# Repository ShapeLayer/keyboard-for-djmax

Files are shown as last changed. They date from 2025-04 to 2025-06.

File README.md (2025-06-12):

# Keyboard for DJMAX RESPECT V

_A project task for &lt;IoT Computing&gt; lecture in computer engineering undergraduate course program._

A keyboard for a PC rhythm game, like DJMAX RESPECT V, EZ2ON, etc that supports key input of up to 10 keys, a knob module(usual rotary encoder), and an I2C OLED display module.

## Getting Started

The controller sketch is designed to have compatibility with any Arduino board that supports the `Keyboard` library like Arduino Leonardo.

However, only Arduino Leonardo has been implemented and tested in reality. So it is recommended to use Arduino Leonardo for this project.

### Hardware Requirements
- Arduino board supports `Keyboard` library  
- 10x switches  
    _(If there aren't enough keyboard key switches, you can use push buttons)_
- 1x rotary encoder
- 1x I2C OLED display module  
    _(I used a 128x32 pixels OLED display. If you use a different size, you may need to adjust the display code.)_

A controller processes the key input designed as a 5x2 key matrix. You have to implement the key matrix circuit. The circuit diagram I used is available in the [`circuits`](./circuits/) directory.

### Printing the Case

If you want to print the case, you can find the 3D model files in the [`models`](./models/) directory.

### Software Requirements

- [u8g2 library](https://github.com/olikraus/u8g2) for OLED display  
    Install it through Arduino Library Manager in Arduino IDE. or refer [`INSTALL.ps1`](./INSTALL.ps1)  
- Configuration
    - [`controller/config.h`](./controller/config.h)  
        Configure the pin numbers of the switches, key output mapping, and others.

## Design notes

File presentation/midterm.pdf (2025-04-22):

# PC 리듬게임을 위한

# 리듬게임 컨트롤러

### 사용 중인 키보드로부터

## 「DJMAX RESPECT V」 플레이 컨트롤러 분리하기

공과대학 컴퓨터정보통신공학과

## 214823 박종현

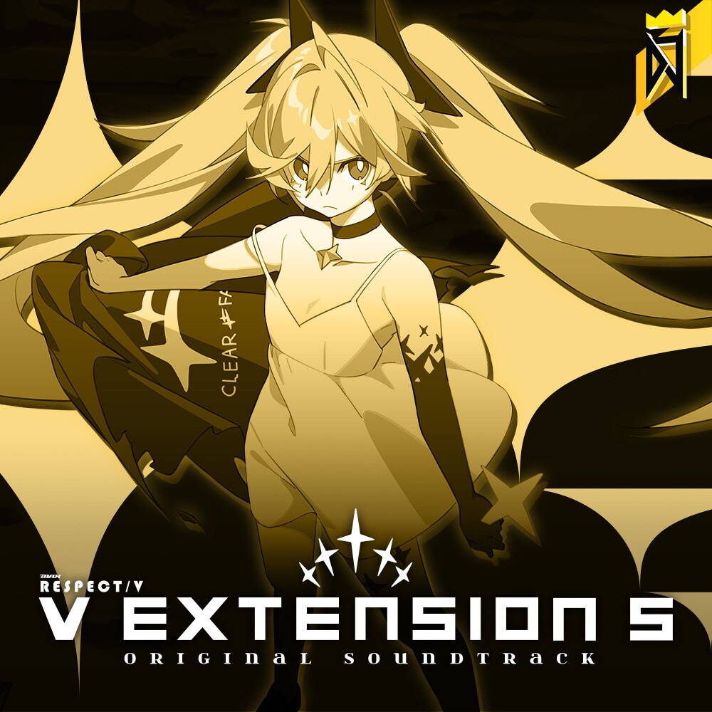
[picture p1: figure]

Source: Rocky Studio

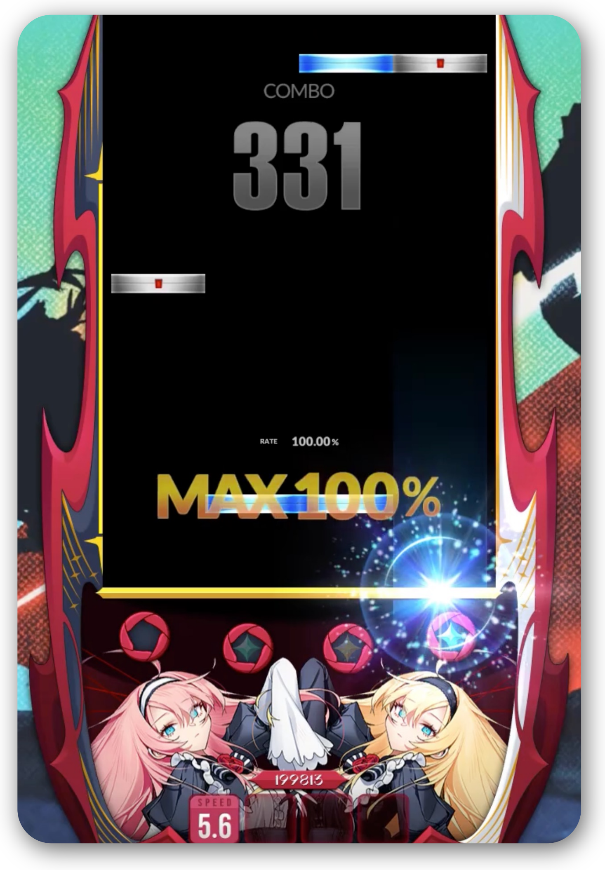
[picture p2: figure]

배경

- 리듬게임은 리듬과 타이밍에 맞춰 곡을 연주
- 정확한 버튼 입력 타이밍을 놓치지 않으려고
강하게 입력

배경

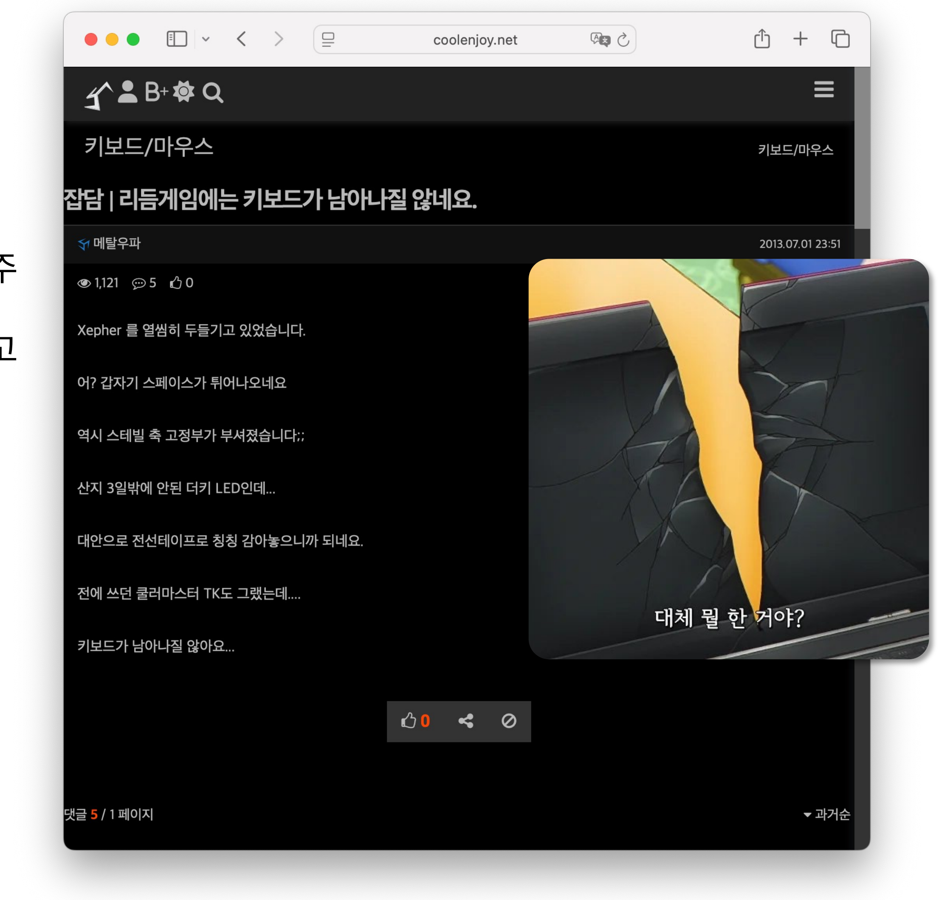
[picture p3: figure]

- 리듬게임은 리듬과 타이밍에 맞춰 곡을 연주
- 정확한 버튼 입력 타이밍을 놓치지 않으려고
강하게 입력
- 키보드 스위치에 무리가 가는 일
- 리듬게임 입력으로 사용하는 키보드 키의
스위치는 다른 키보다 빠르게 소모됨

목표

### - 일반 목적으로 사용하는 키보드와

## 리듬게임 키 입력용 입력 장치의

분리

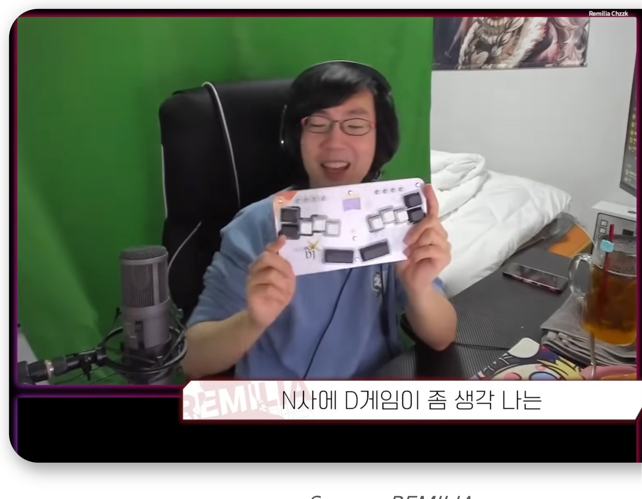
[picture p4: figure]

Source: REMILIA

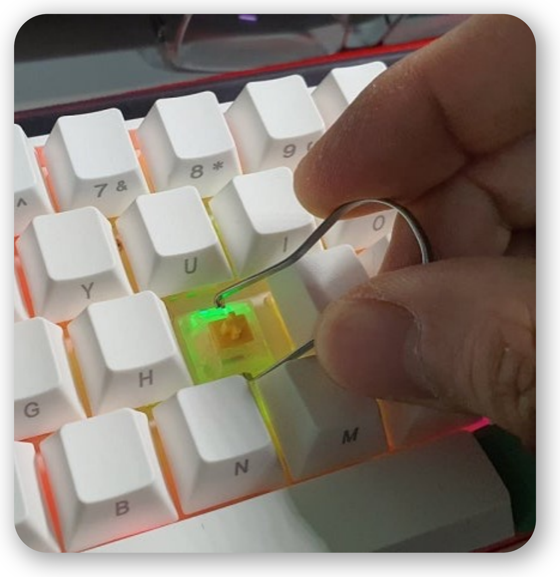
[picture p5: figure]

# 진행 계획

1. 이미 고장난 키보드에서 정상 작동하는 스위 치 추출
2. 추출한 스위치를 아두이노와 연결
3. 스위치 입력 시 아두이노가 PC에 키보드 입 력 신호를 발생시키는 코드 작성
- 사용할 센서: 키보드 클릭 스위치 10개 전후

# 예상되는 문제

- 키보드의 스위치를 아두이노에서 사용할 수 있는가? 내부 회로가 단순한 푸시 버튼 구조가 아닌 경우
- 아두이노가 키보드 입력 신호를 발생할 수 있는가?

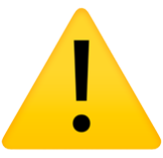
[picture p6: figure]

아두이노에서 연결된 PC로 키보드 입력 신호를 전송하 ⚠ 지 못할 경우

# 확인된 문제

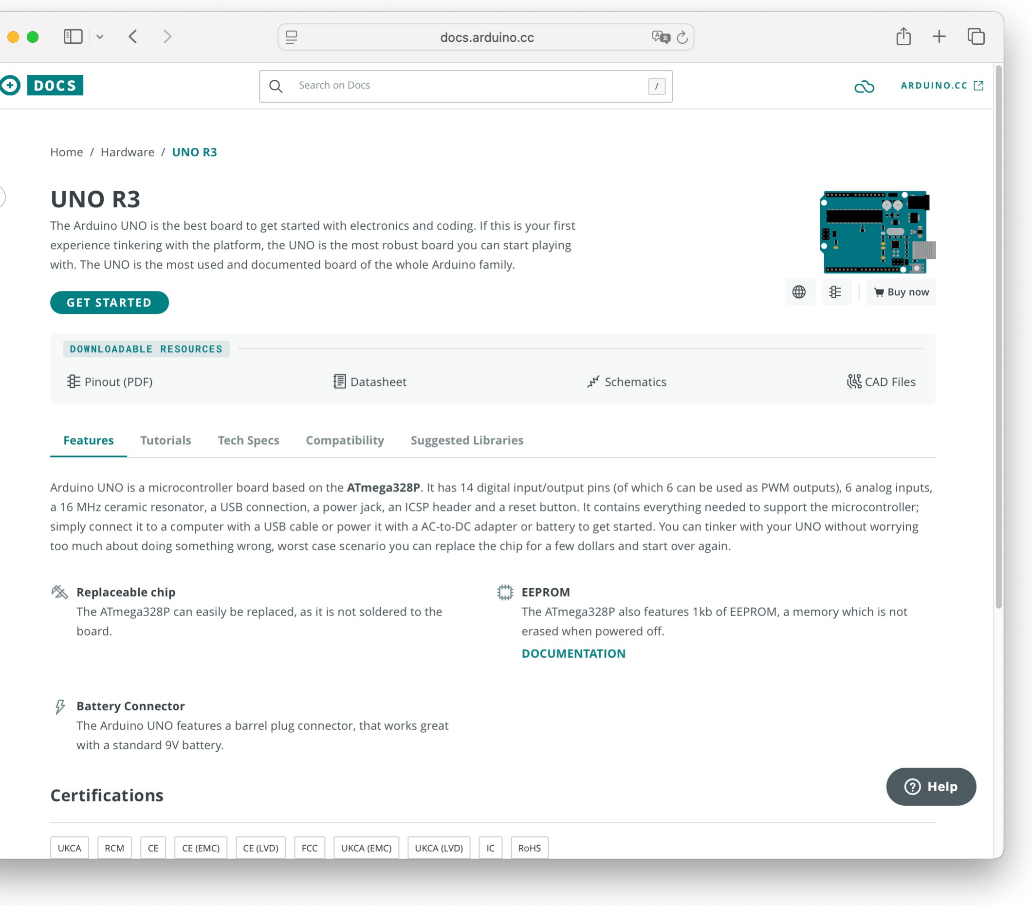
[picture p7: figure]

## 실습에서 사용하는 Arduino Uno R3 모델은

## 키보드 입력에 사용되는 <Keyboard.h> 헤더를

## 사용할 수 없음

# 확인된 문제

## 실습에서 사용하는 Arduino Uno R3 모델은

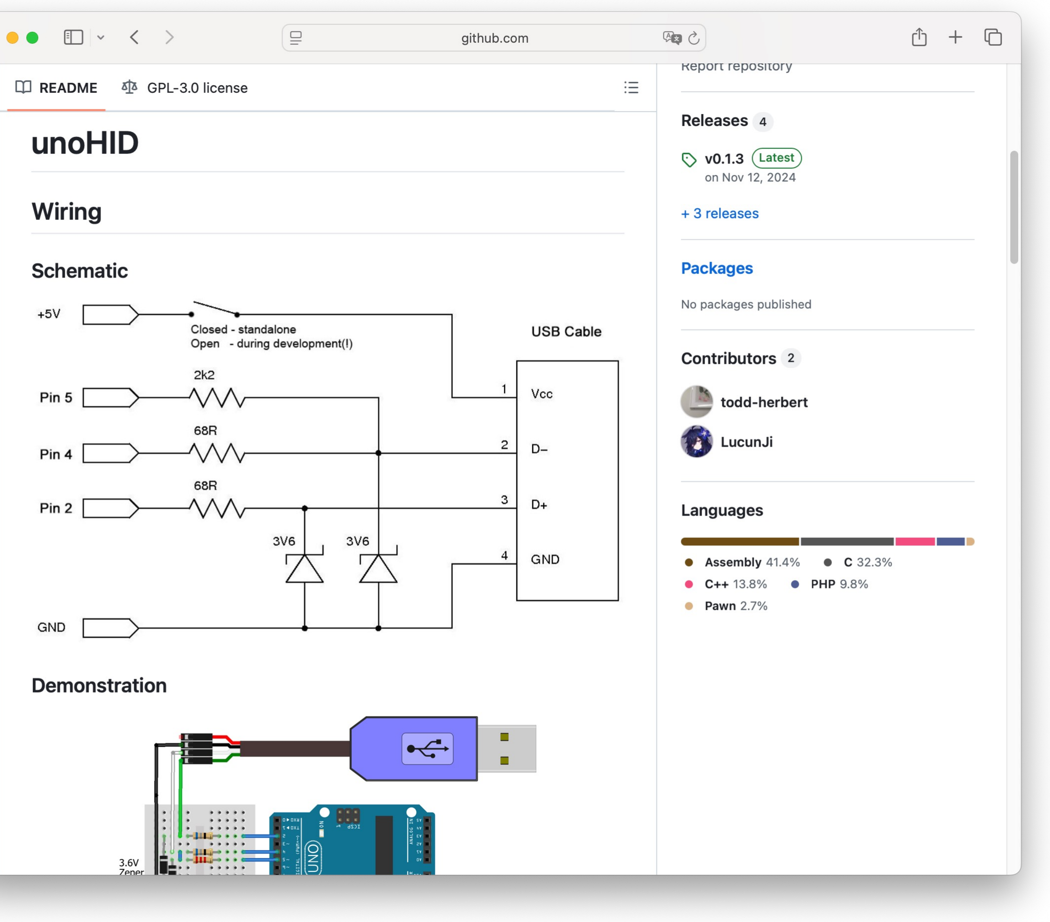
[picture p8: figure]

## 키보드 입력에 사용되는 <Keyboard.h> 헤더를

## 사용할 수 없음

### ⇒ 키보드 입력 신호 발생시키는 코드 구현체 존재

### - 시험 기간 종료 후 정상 동작 확인할 계획

# 진행 계획

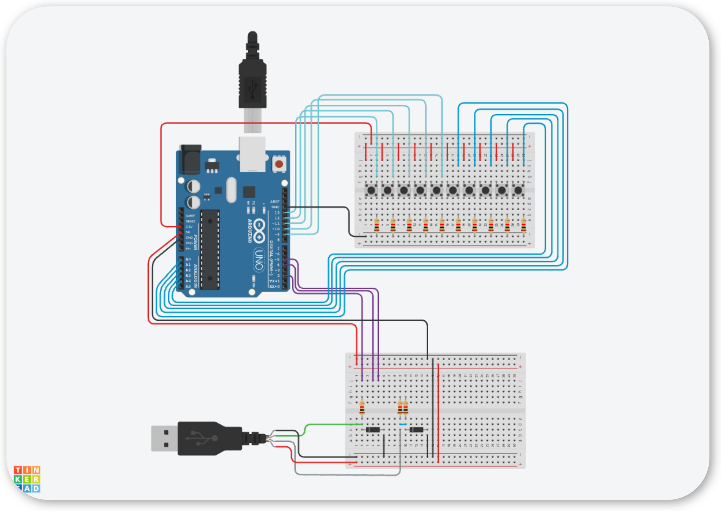
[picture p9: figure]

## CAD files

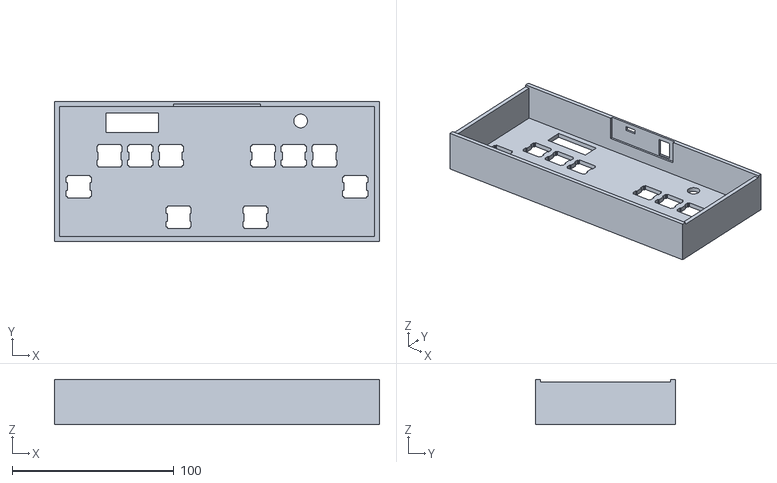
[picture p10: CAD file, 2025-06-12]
models/body.stl
201.0 x 86.7 x 28.0

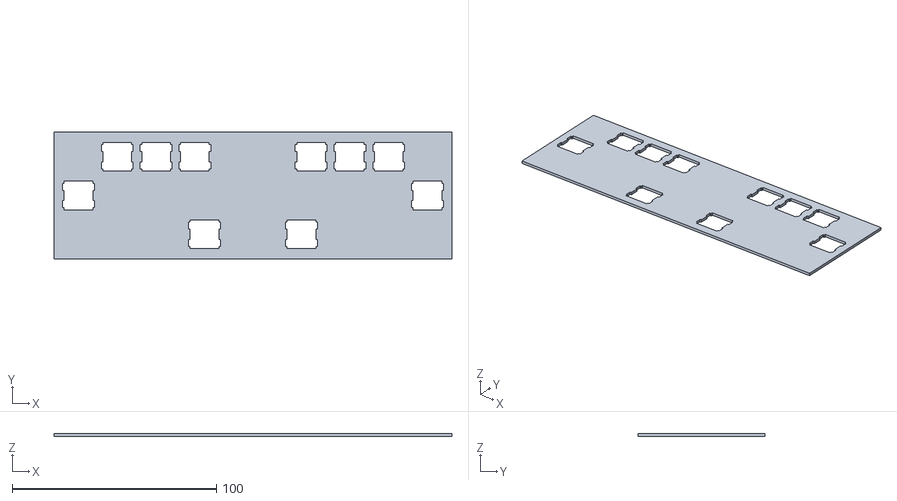
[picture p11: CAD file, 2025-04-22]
models/keyboard-layout/model/keyboard.stl
195.0 x 62.0 x 1.50

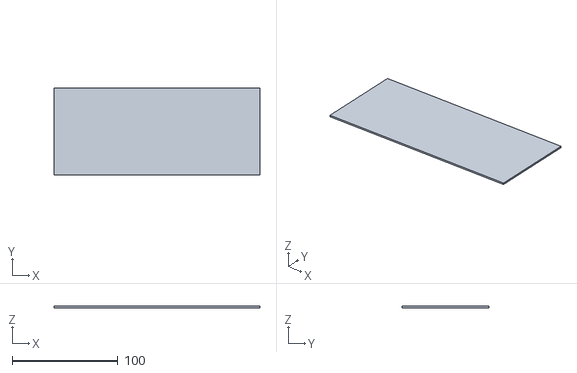
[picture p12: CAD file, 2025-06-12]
models/cover.stl
195.0 x 82.7 x 1.50

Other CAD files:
models/keyboard-layout/model/keyboard.dxf

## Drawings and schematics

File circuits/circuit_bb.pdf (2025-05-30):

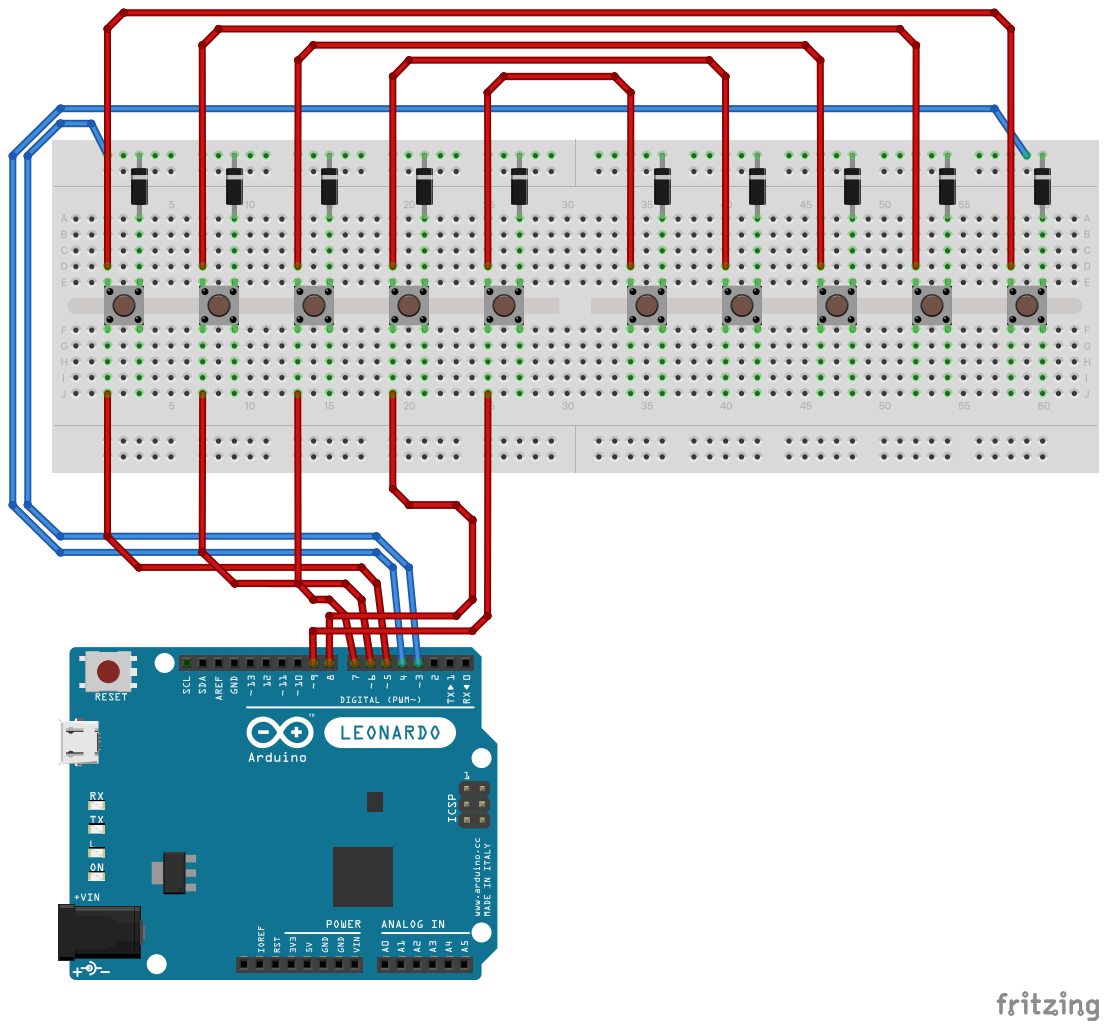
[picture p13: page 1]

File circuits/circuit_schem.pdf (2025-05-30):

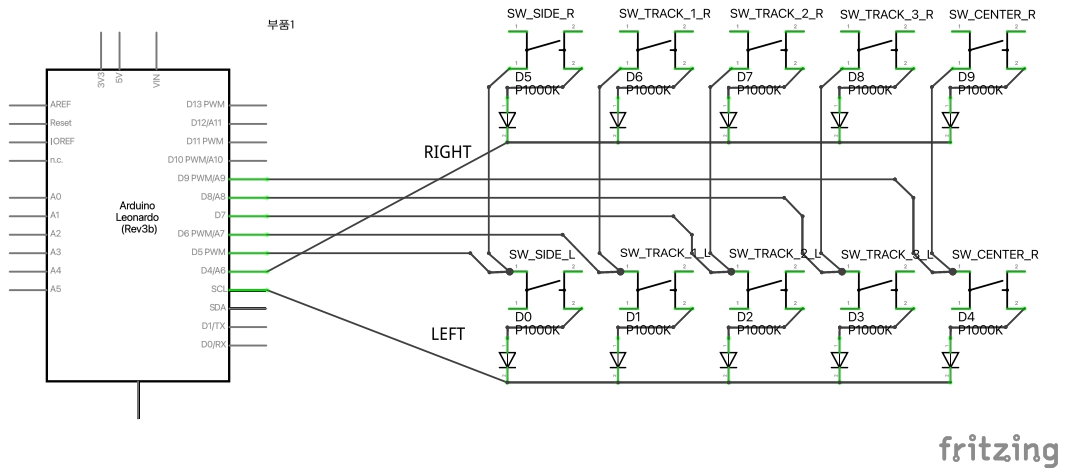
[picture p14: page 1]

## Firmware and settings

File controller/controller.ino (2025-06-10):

#include <Keyboard.h>
#include <U8g2lib.h>
#include "const.h"
#include "context.h"
#include "config.h"
#include "displaystate.h"
#include "displayhandle.h"
#include "keystate.h"
#include "keypress.h"
#include "knobstate.h"
#include "knobrotate.h"

#include "config.h"

context_t context;
display_state_t display_state;
key_set_state_t key_set_state;
knob_state_t knob_state;

void init_pins();

void setup() {
  Serial.begin(9600);
  delay(1000);  // Give Serial time to initialize
  Serial.println("Starting DJMAX Controller...");
  
  context = new_context();
  display_state = new_display_state();
  key_set_state = new_key_set_state();
  knob_state = new_knob_state();

  init_display_pins(&display_state);
  init_key_pins();
  init_knob_pins(&knob_state);
  
  Serial.println("Controller initialized.");
}

void loop() {
  proc_keys_handler(&context, &key_set_state);
  #if KNOB_IS_ENABLED
  proc_knob_handler(&context, &knob_state);
  #endif  // KNOB_IS_ENABLED
  #if DISPLAY_IS_ENABLED
  proc_display_handler(&context, &display_state);
  #endif  // DISPLAY_IS_ENABLED
}

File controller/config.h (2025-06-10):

#ifndef __CONFIG_H__
#define __CONFIG_H__
#include <Keyboard.h>
#include "const.h"

/**
 * Configuration
 * 
 * If you don't want to use a specific pin for keyout or want to disable a specific key,
 * just set the pin to UNDEFINED.
 * i.e. #define KEYOUT_TRACK_1 UNDEFINED
 */

#define KNOB_IS_ENABLED true
#define DISPLAY_IS_ENABLED true

/**
 * Matrix constructed key switch pins
 * 
 * TRACK_SIDE_L = PIN_TRACK_L & PIN_TRACK_SIDE
 * TRACK_5 = PIN_TRACK_R & PIN_TRACK_1
 */
// Key Row in Key Matrix
#define PIN_TRACK_L 2
#define PIN_TRACK_R 3

// Key Column in Key Matrix
#define PIN_TRACK_SIDE 4
#define PIN_TRACK_1 5
#define PIN_TRACK_2 6
#define PIN_TRACK_3 7
#define PIN_TRACK_CENTER 8

// Knob Pins
#define PIN_KNOB_CLK 9
#define PIN_KNOB_DT 10
#define PIN_KNOB_SW 11

// Display Pins
#define PIN_DISPLAY_SDA 12
#define PIN_DISPLAY_SCL 13

/**
 * Keyboard input to connected device
 */
#define KEYOUT_TRACK_SIDE_L KEY_LEFT_SHIFT
#define KEYOUT_TRACK_1 'a'
#define KEYOUT_TRACK_2 's'
#define KEYOUT_TRACK_3 'd'
#define KEYOUT_TRACK_L 'f'
#define KEYOUT_TRACK_R 'j'
#define KEYOUT_TRACK_4 'k'
#define KEYOUT_TRACK_5 'l'
#define KEYOUT_TRACK_6 ';'
#define KEYOUT_TRACK_SIDE_R KEY_RIGHT_SHIFT

#define KEYOUT_KNOB_CW '1'
#define KEYOUT_KNOB_CCW '2'

// Threashold for preventing chattering
#define DEBOUNCE_DELAY 20  // (ms)

// Slicing value for last_changed to prevent overflow
#define LAST_CHANGED_SLICING 4000000000
#define MILLIS_SLICING 4000000000

// Display configuration
// TODO: Improving a content of display required.
#define PLACEHOLDER_DISPLAY_TEXT_ON_INIT "Hello"
#define DISPLAY_TEMPLATE_ON_KNOB_ROTATE_CW "+1"
#define DISPLAY_TEMPLATE_ON_KNOB_ROTATE_CCW "-1"

#define DISPLAY_BACK_TO_IDLE_TIMEOUT 5000  // (ms)

#endif  // __CONFIG_H__

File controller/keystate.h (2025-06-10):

#ifndef __KEYSTATE_H__
#define __KEYSTATE_H__

#include "config.h"
#include "utils.h"

// Definitions
#define KEYID_TRACK_SIDE_L 0
#define KEYID_TRACK_1 1
#define KEYID_TRACK_2 2
#define KEYID_TRACK_3 3
#define KEYID_TRACK_L 4
#define KEYID_TRACK_R 5
#define KEYID_TRACK_4 6
#define KEYID_TRACK_5 7
#define KEYID_TRACK_6 8
#define KEYID_TRACK_SIDE_R 9

#define GET_KEYID_OUTPUT(key) \
  ((key) == KEYOUT_TRACK_SIDE_L ? KEYID_TRACK_SIDE_L : \
   (key) == KEYOUT_TRACK_1 ? KEYID_TRACK_1 : \
   (key) == KEYOUT_TRACK_2 ? KEYID_TRACK_2 : \
   (key) == KEYOUT_TRACK_3 ? KEYID_TRACK_3 : \
   (key) == KEYOUT_TRACK_L ? KEYID_TRACK_L : \
   (key) == KEYOUT_TRACK_R ? KEYID_TRACK_R : \
   (key) == KEYOUT_TRACK_4 ? KEYID_TRACK_4 : \
   (key) == KEYOUT_TRACK_5 ? KEYID_TRACK_5 : \
   (key) == KEYOUT_TRACK_6 ? KEYID_TRACK_6 : \
   (key) == KEYOUT_TRACK_SIDE_R ? KEYID_TRACK_SIDE_R : -1)

typedef struct {
  uint8_t key;
  unsigned long last_changed;
  bool pressed;
} key_state_t;

typedef struct {
  key_state_t track_side_l;
  key_state_t track_1;
  key_state_t track_2;
  key_state_t track_3;
  key_state_t track_l;
  key_state_t track_r;
  key_state_t track_4;
  key_state_t track_5;
  key_state_t track_6;
  key_state_t track_side_r;
} key_set_state_t;

key_state_t new_key_state(uint8_t);
key_set_state_t new_key_set_state();
void init_key_pins();
INLINE void update_last_changed(key_state_t *, unsigned int);
INLINE bool is_in_debounce_period(key_state_t *, unsigned long);

// Implementations
key_state_t new_key_state(uint8_t key) {
  key_state_t state;
  state.key = key;
  state.last_changed = 0;
  state.pressed = false;
  return state;
};

key_set_state_t new_key_set_state() {
  key_set_state_t set_state;
  set_state.track_side_l = new_key_state(KEYOUT_TRACK_SIDE_L);
  set_state.track_1 = new_key_state(KEYOUT_TRACK_1);
  set_state.track_2 = new_key_state(KEYOUT_TRACK_2);
  set_state.track_3 = new_key_state(KEYOUT_TRACK_3);
  set_state.track_l = new_key_state(KEYOUT_TRACK_L);
  set_state.track_r = new_key_state(KEYOUT_TRACK_R);
  set_state.track_4 = new_key_state(KEYOUT_TRACK_4);
  set_state.track_5 = new_key_state(KEYOUT_TRACK_5);
  set_state.track_6 = new_key_state(KEYOUT_TRACK_6);
  set_state.track_side_r = new_key_state(KEYOUT_TRACK_SIDE_R);
  return set_state;
};

void init_key_pins() {
  // Row
  #if PIN_TRACK_L != UNDEFINED
  pinMode(PIN_TRACK_L, OUTPUT);
  digitalWrite(PIN_TRACK_L, HIGH);
  #endif  // PIN_TRACK_L != UNDEFINED
  #if PIN_TRACK_R != UNDEFINED
  pinMode(PIN_TRACK_R, OUTPUT);
  digitalWrite(PIN_TRACK_R, HIGH);
  #endif  // PIN_TRACK_R != UNDEFINED

  // Column
  #if PIN_TRACK_SIDE != UNDEFINED
  pinMode(PIN_TRACK_SIDE, INPUT_PULLUP);
  #endif  // PIN_TRACK_SIDE != UNDEFINED
  #if PIN_TRACK_1 != UNDEFINED
  pinMode(PIN_TRACK_1, INPUT_PULLUP);
  #endif  // PIN_TRACK_1 != UNDEFINED
  #if PIN_TRACK_2 != UNDEFINED
  pinMode(PIN_TRACK_2, INPUT_PULLUP);
  #endif  // PIN_TRACK_2 != UNDEFINED
  #if PIN_TRACK_3 != UNDEFINED
  pinMode(PIN_TRACK_3, INPUT_PULLUP);
  #endif  // PIN_TRACK_3 != UNDEFINED
  #if PIN_TRACK_CENTER != UNDEFINED
  pinMode(PIN_TRACK_CENTER, INPUT_PULLUP);
  #endif  // PIN_TRACK_CENTER != UNDEFINED
}

INLINE void update_last_changed(key_state_t *state, unsigned int value) {
  time_slice(&(state->last_changed));
}

INLINE bool is_in_debounce_period(key_state_t *state, unsigned long now) {
  return time_s_diff(state->last_changed, now) < DEBOUNCE_DELAY;
}

#endif  // __KEYSTATE_H__

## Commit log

2025-05-30 feat: add matrix circuit
    [circuit.fzz]
2025-06-12 chore: Add additional files that used in implementation
    [body.stl, cover.stl, keyboard.dxf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]
